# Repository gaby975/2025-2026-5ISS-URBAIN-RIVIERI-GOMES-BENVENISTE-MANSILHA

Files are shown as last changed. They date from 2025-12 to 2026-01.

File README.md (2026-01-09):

# 2025-2026-5ISS-URBAIN-RIVIERI-GOMES-BENVENISTE-MANSILHA
## Introduction
The objective of this project is to develop an electronic card on which we have integrated a gas sensor manufactured in the clean room at AIME (Inter-University Micro-Nano Electronics Laboratory). The electronic board includes an analog circuit for conditioning the sensor signal, a microcontroller (ESP32) for receiving the conditioned sensor signal and communicating with the other components on the board, a LoRa module for sending sensor data over a LoRa network using Chirpstack, and a buzzer to alert when a gas concentration threshold has been exceeded.

## Gas sensor fabrication
The first step in this project is to manufacture a gas sensor. This sensor was manufactured in a clean room at the AIME (Interuniversity Micro-Nano Electronics Workshop) located on the INSA Toulouse campus. It is a semiconductor-type metal oxide gas sensor based on WO₃ nanoparticles and capable of detecting reducing gases such as ammonia (NH₃) and ethanol vapors.

The sensor is composed of several elements that are worth detailing. First, there are interdigitated aluminum combs on which WO₃ nanoparticles have been deposited and organized by dielectrophoresis. Next, there is an n-doped polysilicon heating resistor, which raises the temperature inside the sensor, improving the surface reaction between the WO₃ nanoparticles and the gas. Finally, there is an aluminum thermistor that measures the temperature inside the sensor.

gas sensor

The manufacturing process for this sensor involves a large number of steps, but the most important ones are the photolithography steps. Photolithography enables the formation of the different layers required for the sensor to function. We start with a Si/SiO₂ substrate onto which a layer of polysilicon is deposited using the Low Pressure Chemical Vapor Deposition (LPCVD) technique. The polysilicon is n-doped by diffusing phosphorus (P) into it. An initial photolithography step is used to obtain the correct pattern for the polysilicon layer. A second photolithography step is then used to create the SiO₂ insulation layer with openings. Finally, a last photolithography step is used to create the electrodes from a deposited aluminum layer.

gas sensor process

## Simulation on LTspice
As part of this project, one part was dedicated to designing a stage for conditioning/amplifying the signal delivered by the gas sensor. This signal, which is processed by the ESP32-WROOM microcontroller ADC, must be readable and processable by the latter. To do this, the conditioning stage was designed around the component LTC1050, which was used because It has a really low input voltage offset as well as a good common-mode tolerance and relatively low voltage drift maintain the integrity and accuracy of the 10mV voltage measured at the terminals of R1. This is the schematic we get on LTSpice:

ltspice_trans_impedance_amplifier

To ensure good signal quality, several filters have been installed. A bandwidth of 1 Hz is sufficient to extract useful information from the sensor. Three filters have been used: 

- a passive filter F1 at the input to prevent HF noise from causing distortion in the input stages: R0, C1, and R1.
- an active filter F2 at the operational amplifier level : R3 and C4.
- a passive filter F3 at the output of the circuit to remove noise introduced during processing (power supply noise, clock noise) : C2 and R6.

ltspice_filter_table

Using an LTspice simulation, we were able to determine the frequency response (frequency gain) of each filter and also of the entire circuit. The Bode diagram of the active filter is as follows :

ltspice_fc2

The Bode diagram of the passive filter at the output of the circuit is as follows :

ltspice_fc3

Finally, we find the following frequency response for the complete setup (gain and phase):

ltspice_fullbode

## PCB design on KiCad

After all these simulation and in parallel with the software development of the ESP32 and its interaction with the LoRa module, the electronic board diagram was entered and the complete PCB routing was carried out. The electronic board diagram includes female connectors to facilitate the integration of the microcontroller and the LoRa module. With that a two-pins connector is included to ensure the correct power supply to the gas sensor's heating element. A buzzer has also been added to provide audible alerts when gas is detected, as well as a button for various uses, such as sending data or requesting a connection with the LoRa gateway. 

#### Here is the electrical schematic of the board:

Capture d'écran 2026-01-06 163123

#### We gathered all the components we used for this board: 

| Reference | Quantity | Value / Description | 
|---|---|---|
| BZ1 | 1 | Buzzer | 
| C1, C3, C4 | 3 | 100 nF | 
| C2 | 1 | 1 µF | 
| J1 | 1 | Connector  1x02 | 
| J2 | 1 | Connector  module LoRa | 
| J3 | 1 | Connector  femelle ESP | 
| R1, R6, R8 | 3 | 10 kΩ | 
| R2, R4 | 2 | 100 kΩ | 
| R3, R5 | 2 | 1 kΩ | 
| SW2 | 1 | Push button | 
| U2 | 1 | Gaz Sensor | 
| U3 | 1 | LTC1050CN8-PBF (AOP) | 

The electronic board diagram done, the PCB routing has been done and the goal was to minimized the size of the whole card. As a result, we decided to route on both sides (top and bottom) to save space and make it compact and to outsource PCB manufacturing to JLC PCB to have a more clean product. 

#### Here is the final PCB layout: 

Capture d'écran 2026-01-06 163302

## Embedded code

This program (Arduino/ESP32) reads a **gas sensor** on an analog input, computes an estimated value in **PPM**, then sends it to **ChirpStack** via an **RN2483** module using **LoRaWAN OTAA**.
Transmission happens **every 5 seconds** or **when the button is pressed**. An **LED** indicates sending, and a **buzzer** beeps on each transmission to indicate **SUCCESS** or **FAILURE**.

---

### Required hardware

* ESP32
* RN2xx3 LoRa module (RN2483 / RN2903) connected via UART
* Gas sensor (analog output)
* Button (digital input)
* Buzzer (digital output)
* Built-in LED (or external LED)

---

### Pinout (ESP32 ↔ RN2xx3 / Sensors / I/O)

#### LoRa RN2483 (UART2 / Serial2)

| Function | ESP32 GPIO | Direction | RN2483 |
| --- | ---: | --- | --- |
| UART2 RX | **GPIO16** | ESP32 receives | RN2483 **TX**  |
| UART2 TX | **GPIO17** | ESP32 sends | RN2483 **RX**  |
| LoRa Reset |  **GPIO4** | output | RN2483 **RST** |
| Power | **3.3V** | — | VCC |
| Ground | **GND** | — | GND |

---

#### Sensors / Button / Buzzer / LED

| Element | ESP32 GPIO | Type | Note |
| --- | ---: | --- | --- |
| Gas sensor (analog) | **GPIO36** | ADC1 | reads the analog value after the filter |
| Button | **GPIO22** | input  | wired in pull-up mode |
| Buzzer | **GPIO23** | output | beep on each send |
| LED (built-in) |  **GPIO2** | output | LED on while sending |
| “Temperature” (analog ) |  **GPIO2** | input  | reads the analog value aftera a voltage divider |

---

### Dependencies

#### Arduino library

* `rn2xx3`

Include in the code:

```cpp
#include <rn2xx3.h>
```

## Node-RED

The Node-RED flow listens to an MQTT topic (ChirpStack uplinks), **extracts the `data` field**, **decodes it from Base64**, then **converts it to a base-10 number**. The value is displayed on a **dashboard** (gauge + history). A **“DANGER!”** alert (text + audio) is triggered above a threshold.

### Features

* **MQTT In**

  * Broker: `srv-chirpstack.insa-toulouse.fr:1883`
  * Topic: `application/2fc05488-1aaa-49cf-a35a-cf58fae84647/device/0004a30b0110c16d/event/up`
  * QoS: `2`
* **Decoding**

  * Extract `payload.data`
  * `Base64 -> UTF-8 -> Number (base 10)`
* **Dashboard**

  * Gauge `Actual_Sensor_Value` (0 → 8000, green/yellow/red zones)
  * Chart `Sensor_value_History` (~1h history)
* **Alert**

  * If `value >= 6000` → `DANGER!` + audio + text

### Prerequisites

* Node-RED installed
* Network access to the MQTT broker
* Node-RED modules:

  * `node-red-dashboard` (the flow indicates config **3.6.6**)
  * The `ui_audio` node may require an additional module depending on your setup (often `node-red-contrib-ui-audio`)

Example installation:

```bash
cd ~/.node-red
npm install node-red-dashboard
# if needed (if ui_audio is "unknown node type")
npm install node-red-contrib-ui-audio
```

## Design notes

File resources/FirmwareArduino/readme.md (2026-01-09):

# ESP32 + RN2xx3 (LoRaWAN OTAA) — Capteur Gaz, Calcul PPM, Envoi TTN

Ce programme (Arduino/ESP32) lit un **capteur de gaz** sur une entrée analogique, calcule une estimation en **PPM**, puis l’envoie sur **The Things Network (TTN)** via un module **RN2xx3** en **LoRaWAN OTAA**.  
L’envoi se fait **toutes les 5 secondes** ou **sur appui du bouton**. Une **LED** indique l’envoi et un **buzzer** bippe à chaque transmission.

---

## Matériel requis

- ESP32
- Module LoRa RN2xx3 (RN2483 / RN2903) connecté en UART
- Capteur de gaz (sortie analogique)
- Bouton (entrée digitale)
- Buzzer (sortie digitale)
- LED intégrée (ou LED externe)

---

## Pinout (ESP32 ↔ RN2xx3 / Capteurs / I/O)

### LoRa RN2xx3 (UART2 / Serial2)

| Fonction | ESP32 GPIO | Sens | RN2xx3 |
| --- | ---: | --- | --- |
| UART2 RX | **GPIO16** | ESP32 reçoit | **TX** du RN2xx3  |
| UART2 TX | **GPIO17** | ESP32 émet | **RX** du RN2xx3  |
| Reset LoRa |  **GPIO4** | sortie | **RST** du RN2xx3 |
| Alimentation | **3.3V** | — | VCC |
| Masse | **GND** | — | GND |

---

### Capteurs / Bouton / Buzzer / LED

| Élément | ESP32 GPIO | Type | Remarque |
| --- | ---: | --- | --- |
| Capteur Gaz (analog) | **GPIO36** | ADC1 | `analogRead(GAS_PIN)` |
| Bouton | **GPIO22** | entrée | dans ton code : `INPUT` (souvent mieux en `INPUT_PULLUP`) |
| Buzzer | **GPIO23** | sortie | bip à chaque envoi |
| LED (intégrée) |  **GPIO2** | sortie | LED pendant TX |
| “Température” (actuel) |  **GPIO2** | ❌ | **Conflit** avec LED + **pas ADC** |

---

## Dépendances

### Librairie Arduino

- `rn2xx3`

Import dans le code :

```cpp
#include <rn2xx3.h>

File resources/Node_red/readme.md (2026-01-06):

# Node-RED MQTT (ChirpStack)

Ce flow Node-RED écoute un topic MQTT (uplinks ChirpStack), **extrait le champ `data`**, le **décode du Base64** puis le **convertit en nombre base 10**. La valeur est affichée sur un **dashboard** (jauge + historique). Une alerte **“DANGER!”** (texte + audio) est déclenchée au-dessus d’un seuil. 

## Fonctionnalités

- **MQTT In**
  - Broker : `srv-chirpstack.insa-toulouse.fr:1883`
  - Topic : `application/2fc05488-1aaa-49cf-a35a-cf58fae84647/device/0004a30b0110c16d/event/up`
  - QoS : `2` 
- **Décodage**
  - Extraction de `payload.data`
  - `Base64 -> UTF-8 -> Number (base 10)` 
- **Dashboard**
  - Jauge `Actual_Sensor_Value` (0 → 8000, zones vert/jaune/rouge)
  - Courbe `Sensor_value_History` (historique ~1h)
- **Alerte**
  - Si `valeur >= 6000` → `DANGER!` + audio + texte 

## Prérequis

- Node-RED installé
- Accès réseau au broker MQTT
- Modules Node-RED :
  - `node-red-dashboard` (le flow indique une config en **3.6.6**) 
  - Le node `ui_audio` peut nécessiter un module additionnel selon ton install (souvent `node-red-contrib-ui-audio`). 

Installation (exemple) :

```bash
cd ~/.node-red
npm install node-red-dashboard
# si besoin (si ui_audio est "unknown node type")
npm install node-red-contrib-ui-audio

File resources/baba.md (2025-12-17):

fichier keep, pour garder nos informations en toute securite
avec lui, pas de problemes lors de la suppression de fichiers

consignes: https://moodle.insa-toulouse.fr/pluginfile.php/228642/mod_resource/content/0/Consignes_ISS_SmartDevices_2025_2026_ANGLAIS.pdf
cours: https://moodle.insa-toulouse.fr/pluginfile.php/187398/mod_resource/content/0/Cours_TD_TP_OpenSourceHardware_2024_2025_ISS_GP_ANGLAIS.pdf

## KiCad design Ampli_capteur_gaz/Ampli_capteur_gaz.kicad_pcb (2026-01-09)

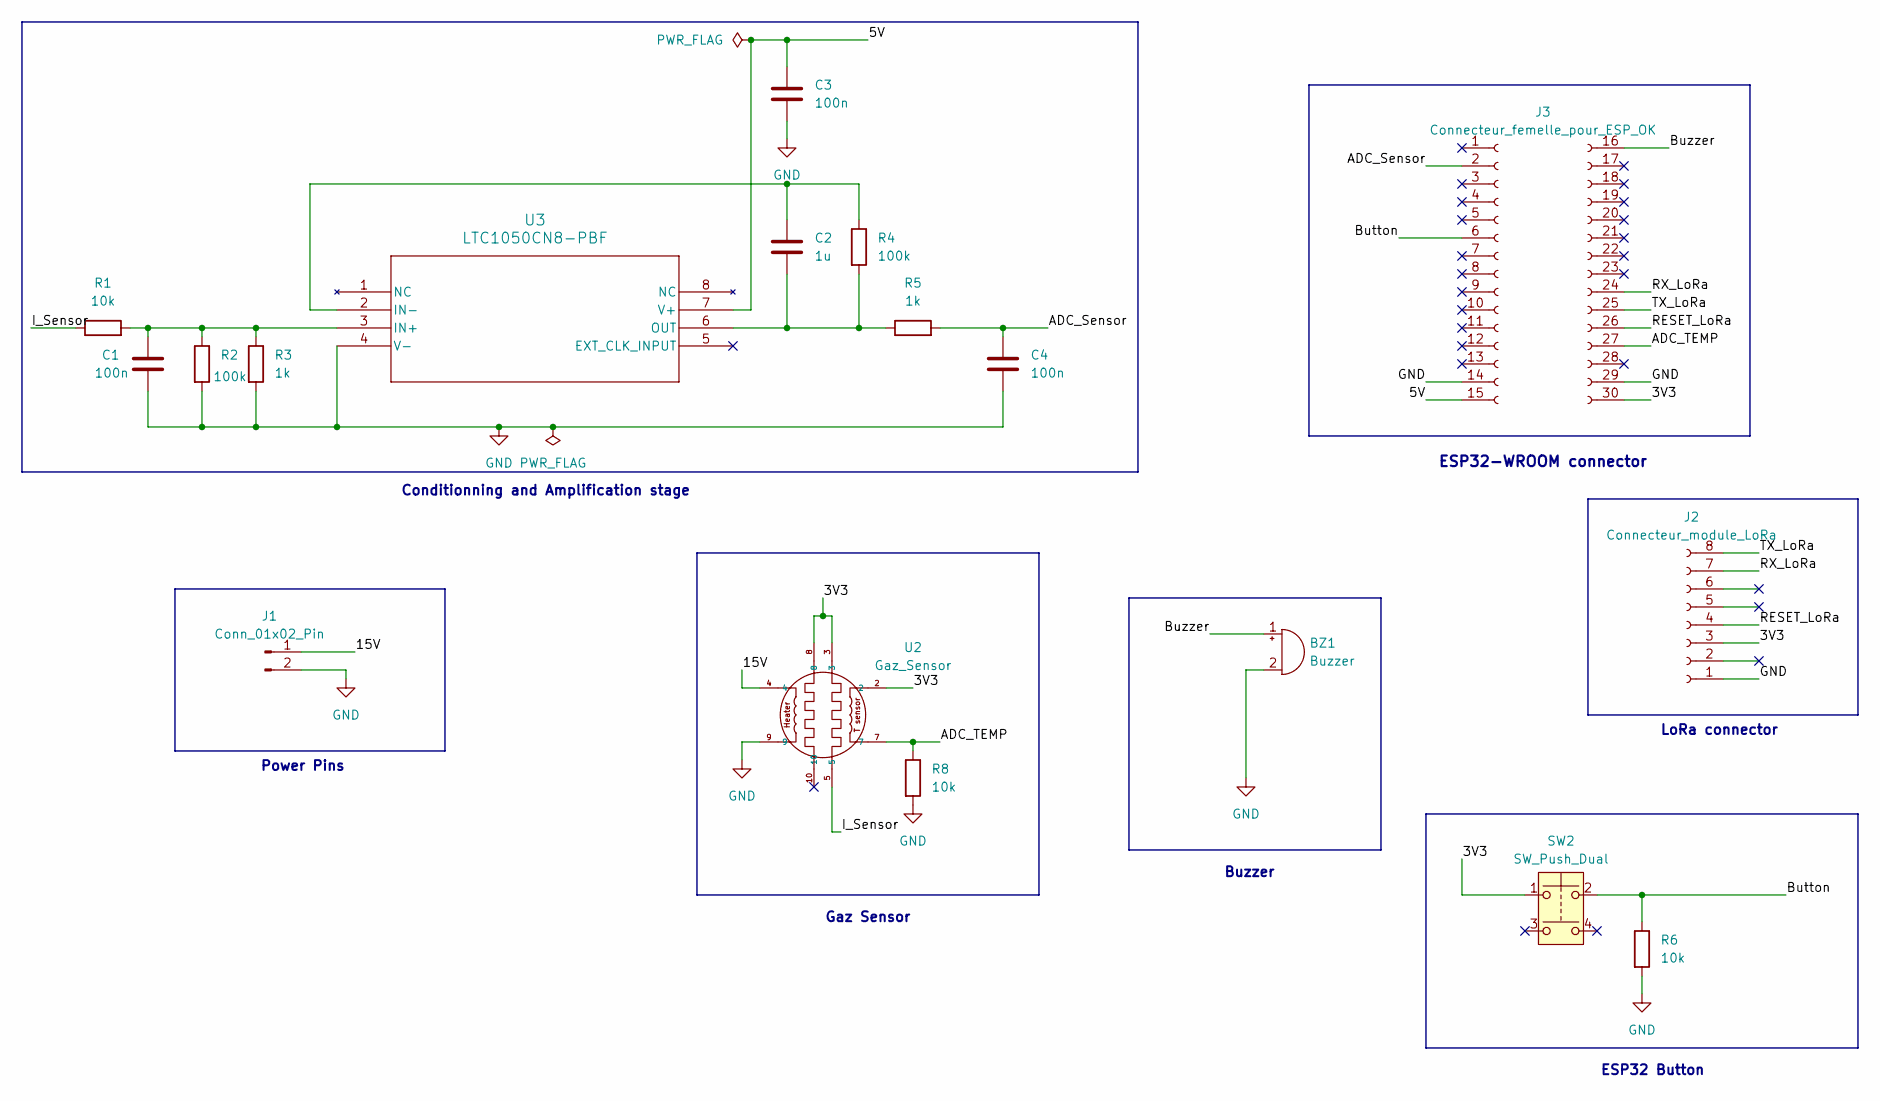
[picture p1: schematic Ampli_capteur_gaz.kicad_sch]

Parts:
BZ1: Buzzer; Buzzer_12x9.5RM7.6
C1, C3, C4: 100n; C_1206_3216Metric_Pad1.33x1.80mm_HandSolder
C2: 1u; C_1206_3216Metric_Pad1.33x1.80mm_HandSolder
J1: Conn_01x02_Pin; PinHeader_1x02_P2.54mm_Vertical
J2: Connecteur_module_LoRa; PinSocket_1x08_P2.54mm_Vertical
J3: Connecteur_femelle_pour_ESP_OK; Connecteur femelle ESP
R1, R6, R8: 10k; R_1206_3216Metric_Pad1.30x1.75mm_HandSolder
R2, R4: 100k; R_1206_3216Metric_Pad1.30x1.75mm_HandSolder
R3, R5: 1k; R_1206_3216Metric_Pad1.30x1.75mm_HandSolder
SW2: SW_Push_Dual; SW_PUSH-12mm
U2: Gaz_Sensor; TO-5-10
U3: LTC1050CN8-PBF; PDIP-8_N_LIT

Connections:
/3V3: J2.3, J3.30 (Pin_1), SW2.1, U2.2, U2.3, U2.8
/5V: C3.1, J3.15, U3.7 (V+)
/15V: J1.1, U2.4
/ADC_Sensor: C4.1, J3.2, R5.2
/ADC_TEMP: J3.27, R8.1, U2.7
/Button: J3.6, R6.1, SW2.2
/Buzzer: BZ1.1 (+), J3.16 (Pin_15)
/I_Sensor: R1.1, U2.5
/RESET_LoRa: J2.4, J3.26 (Pin_5)
/RX_LoRa: J2.7, J3.24
/TX_LoRa: J2.8, J3.25 (Pin_6)
GND: BZ1.2 (-), C1.2, C3.2, C4.2, J1.2, J2.1, J3.14, J3.29 (Pin_2), R2.2, R3.2, R6.2, R8.2, U2.9, U3.4 (V-)
unnamed: C1.1, R1.2, R2.1, R3.1, U3.3 (IN+)
unnamed: C2.1, R4.1, U3.2 (IN-)
unnamed: C2.2, R4.2, R5.1, U3.6 (OUT)

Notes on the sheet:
ESP32 Button
LoRa connector
Power Pins
Buzzer
Conditionning and Amplification stage
ESP32-WROOM connector
Gaz Sensor

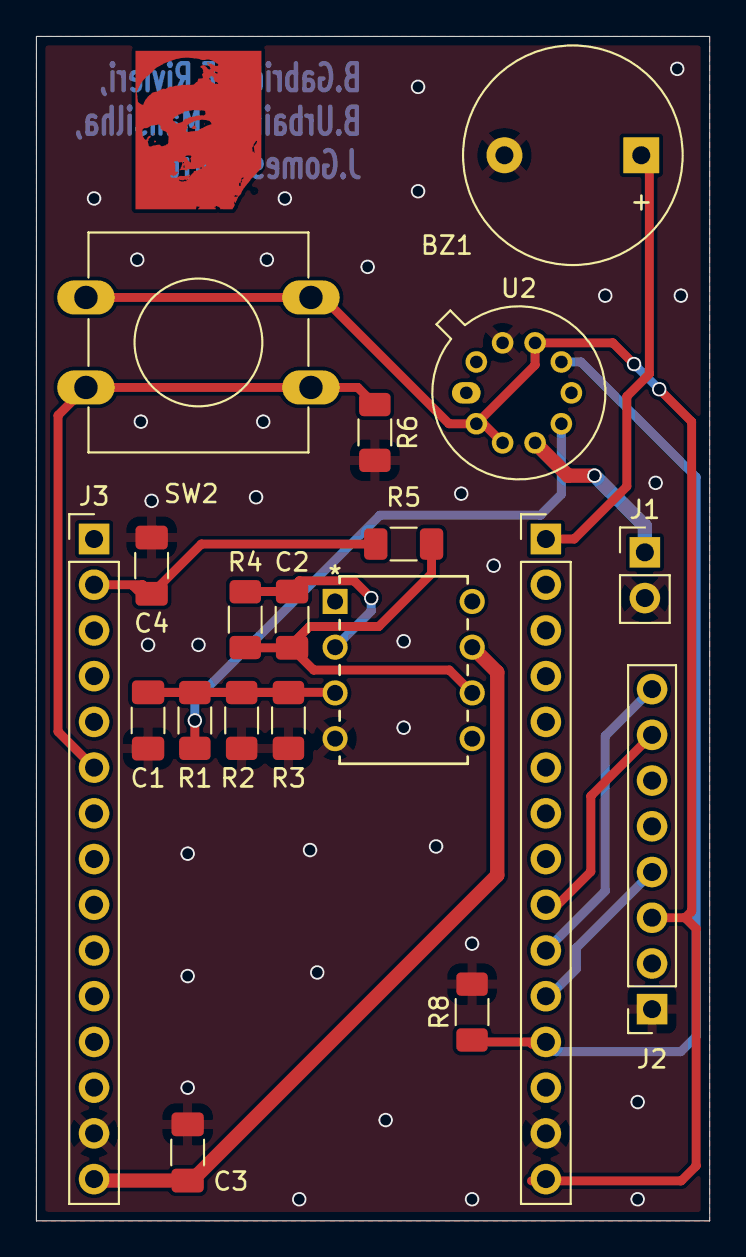
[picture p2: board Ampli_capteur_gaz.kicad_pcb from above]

Board: 2 copper layers, 37.4 x 65.8 mm, 18 parts (0 on the bottom side), 15 nets.

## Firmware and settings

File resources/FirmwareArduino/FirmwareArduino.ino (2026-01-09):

#include <rn2xx3.h>

// --- Choix des pins ESP32 ---
static const int LORA_RX_PIN = 16;   // ESP32 reçoit (RX2)  <- TX du module Lora
static const int LORA_TX_PIN = 17;   // ESP32 émet   (TX2)  -> RX du module Lora
static const int LORA_RST_PIN = 4;   // Reset module Lora
static const int LED_PIN = 2;        // LED intégrée
static const int BUZ_PIN = 23;       // Buzzer du shield
static const int BUT_PIN = 22;       // Bouton du shield
static const int GAS_PIN = 36;       // Capteur AIME
static const int TEMP_PIN = 2;       // Capteur AIME

rn2xx3 myLora(Serial2);
int lastSend = 0;
const float R1 = 100000;
const float R3 = 1000;
const float R2 = 100000;
const float R5 = 10000;
const float GAIN = 1+(R2/R3);
const float VCC = 3.3; 

void led_on()  { digitalWrite(LED_PIN, HIGH); }
void led_off() { digitalWrite(LED_PIN, LOW);  }
void buz_on()  { digitalWrite(BUZ_PIN, HIGH);  }
void buz_off() { digitalWrite(BUZ_PIN, LOW);  }

void initialize_radio()
{
  pinMode(LORA_RST_PIN, OUTPUT);
  digitalWrite(LORA_RST_PIN, LOW);
  delay(500);
  digitalWrite(LORA_RST_PIN, HIGH);

  delay(100);
  while (Serial2.available()) Serial2.read();

  // Comme code d'origine (module souvent en 57600 par défaut)
  myLora.autobaud();

  String hweui = myLora.hweui();
  while (hweui.length() != 16) {
    Serial.println("Communication RN2xx3 KO. Verifie cablage/alimentation.");
    Serial.println(hweui);
    delay(5000);
    hweui = myLora.hweui();
  }

  Serial.print("DevEUI (OTAA) :");
  Serial.println(myLora.hweui());
  Serial.print("Firmware :");
  Serial.println(myLora.sysver());

  Serial.println("Trying to join TTN (OTAA) ...");

  // --- OTAA (ATTENTION clés en clair ici) ---
  const char *appEui = "70B3D57ED00001A6";
  const char *appKey = "e31cda50a5c44300005ab3b765549a99";

  bool join_result = myLora.initOTAA(appEui, appKey);

  while (!join_result) {
    Serial.println("Join OTAA impossible. Verifie clés / couverture.");
    delay(60000);
    join_result = myLora.initOTAA(appEui, appKey);
  }
  Serial.println("Successfully joined TTN");
}

void setup()
{
  pinMode(LED_PIN, OUTPUT);
  pinMode(BUZ_PIN, OUTPUT);
  pinMode(BUT_PIN, INPUT);
  led_on();

  Serial.begin(115200); // Console PC

  // UART2: (baud, config, RX, TX)
  Serial2.begin(9600, SERIAL_8N1, LORA_RX_PIN, LORA_TX_PIN);

  Serial.println("Startup ESP32 + RN2xx3");
  initialize_radio();

  myLora.tx("TTN Mapper ESP32 node");
  led_off();
  delay(2000);
}

void loop()
{
  // MESURES BOUTON + GAS + TEMPERATURE
  int buttun = digitalRead(BUT_PIN);
  float gas_value = analogRead(GAS_PIN);
  Serial.println(gas_value);
  int temp_value = analogRead(TEMP_PIN);
  gas_value = gas_value*3.3/4095;
  Serial.println(gas_value);

  // CALCULS DES VALEURS
  float resistance = 0;
  if (gas_value != 0){ resistance = R1*GAIN*(VCC/gas_value)-R5-R1; }
  
  Serial.println(resistance);
  float ppm_value = resistance/1396;
  Serial.println(ppm_value);

  Serial.println(buttun);

  // ENVOIE TOUT LES 5 SECONDES
  if (buttun || (millis()-lastSend)>5000){
    lastSend = millis();

    led_on();

    Serial.print("## Envoi en cours : ");
    Serial.println(ppm_value);
    TX_RETURN_TYPE r = myLora.tx(String(ppm_value));
    Serial.print("TX result: ");
    if ((int)r == 1){
      Serial.println("SUCCESS");
    }else{
      Serial.println("FAIL");
    }
    
    led_off();

    buz_on();
    delay(200);
    buz_off();
    delay(1000);

  }else{
    buz_off();
  }
  delay(10);
}

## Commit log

2026-01-09 KiCad files added
    [Ampli_capteur_gaz-B_Cu.gbr, Ampli_capteur_gaz-B_Silkscreen.gbr, Ampli_capteur_gaz-Edge_Cuts.gbr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]
2026-01-09 Kicad update
